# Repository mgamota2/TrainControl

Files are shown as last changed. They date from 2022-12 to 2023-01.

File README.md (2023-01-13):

# TrainControl

## Hardware

Wall Adapter - 18V DC Output
https://www.digikey.com/en/products/detail/triad-magnetics/WSU180-1000/3094965

Power Plug
https://www.digikey.com/en/products/detail/w%C3%BCrth-elektronik/694106301002/5047522

L293D H-Bridge
https://www.digikey.com/en/products/detail/stmicroelectronics/L293D/634700

18V-5V Converter
https://www.digikey.com/en/products/detail/mornsun-america-llc/URB4805S-3WR3/16348323

Raspberry Pi Pico W
https://www.digikey.com/en/products/detail/raspberry-pi/SC0918/16608263

MOSFETs(NMOS)
https://www.mouser.com/ProductDetail/Panjit/PJA3404_R1_00001?qs=sPbYRqrBIVkiUO9ZInE3tw%3D%3D

Cap(100uF)
https://www.digikey.com/en/products/detail/panasonic-electronic-components/ECA-1HM101B/268482

Cap(0.1uF)
https://www.mouser.com/ProductDetail/KEMET/C1210C104K1RAC?qs=0OaNwhvMTe1%2FSOzgnjC6ew%3D%3D

Cap(1 uF)
https://www.mouser.com/ProductDetail/Samsung-Electro-Mechanics/CL32B105KBHNNNE?qs=349EhDEZ59rXY4nCVEMdbA%3D%3D

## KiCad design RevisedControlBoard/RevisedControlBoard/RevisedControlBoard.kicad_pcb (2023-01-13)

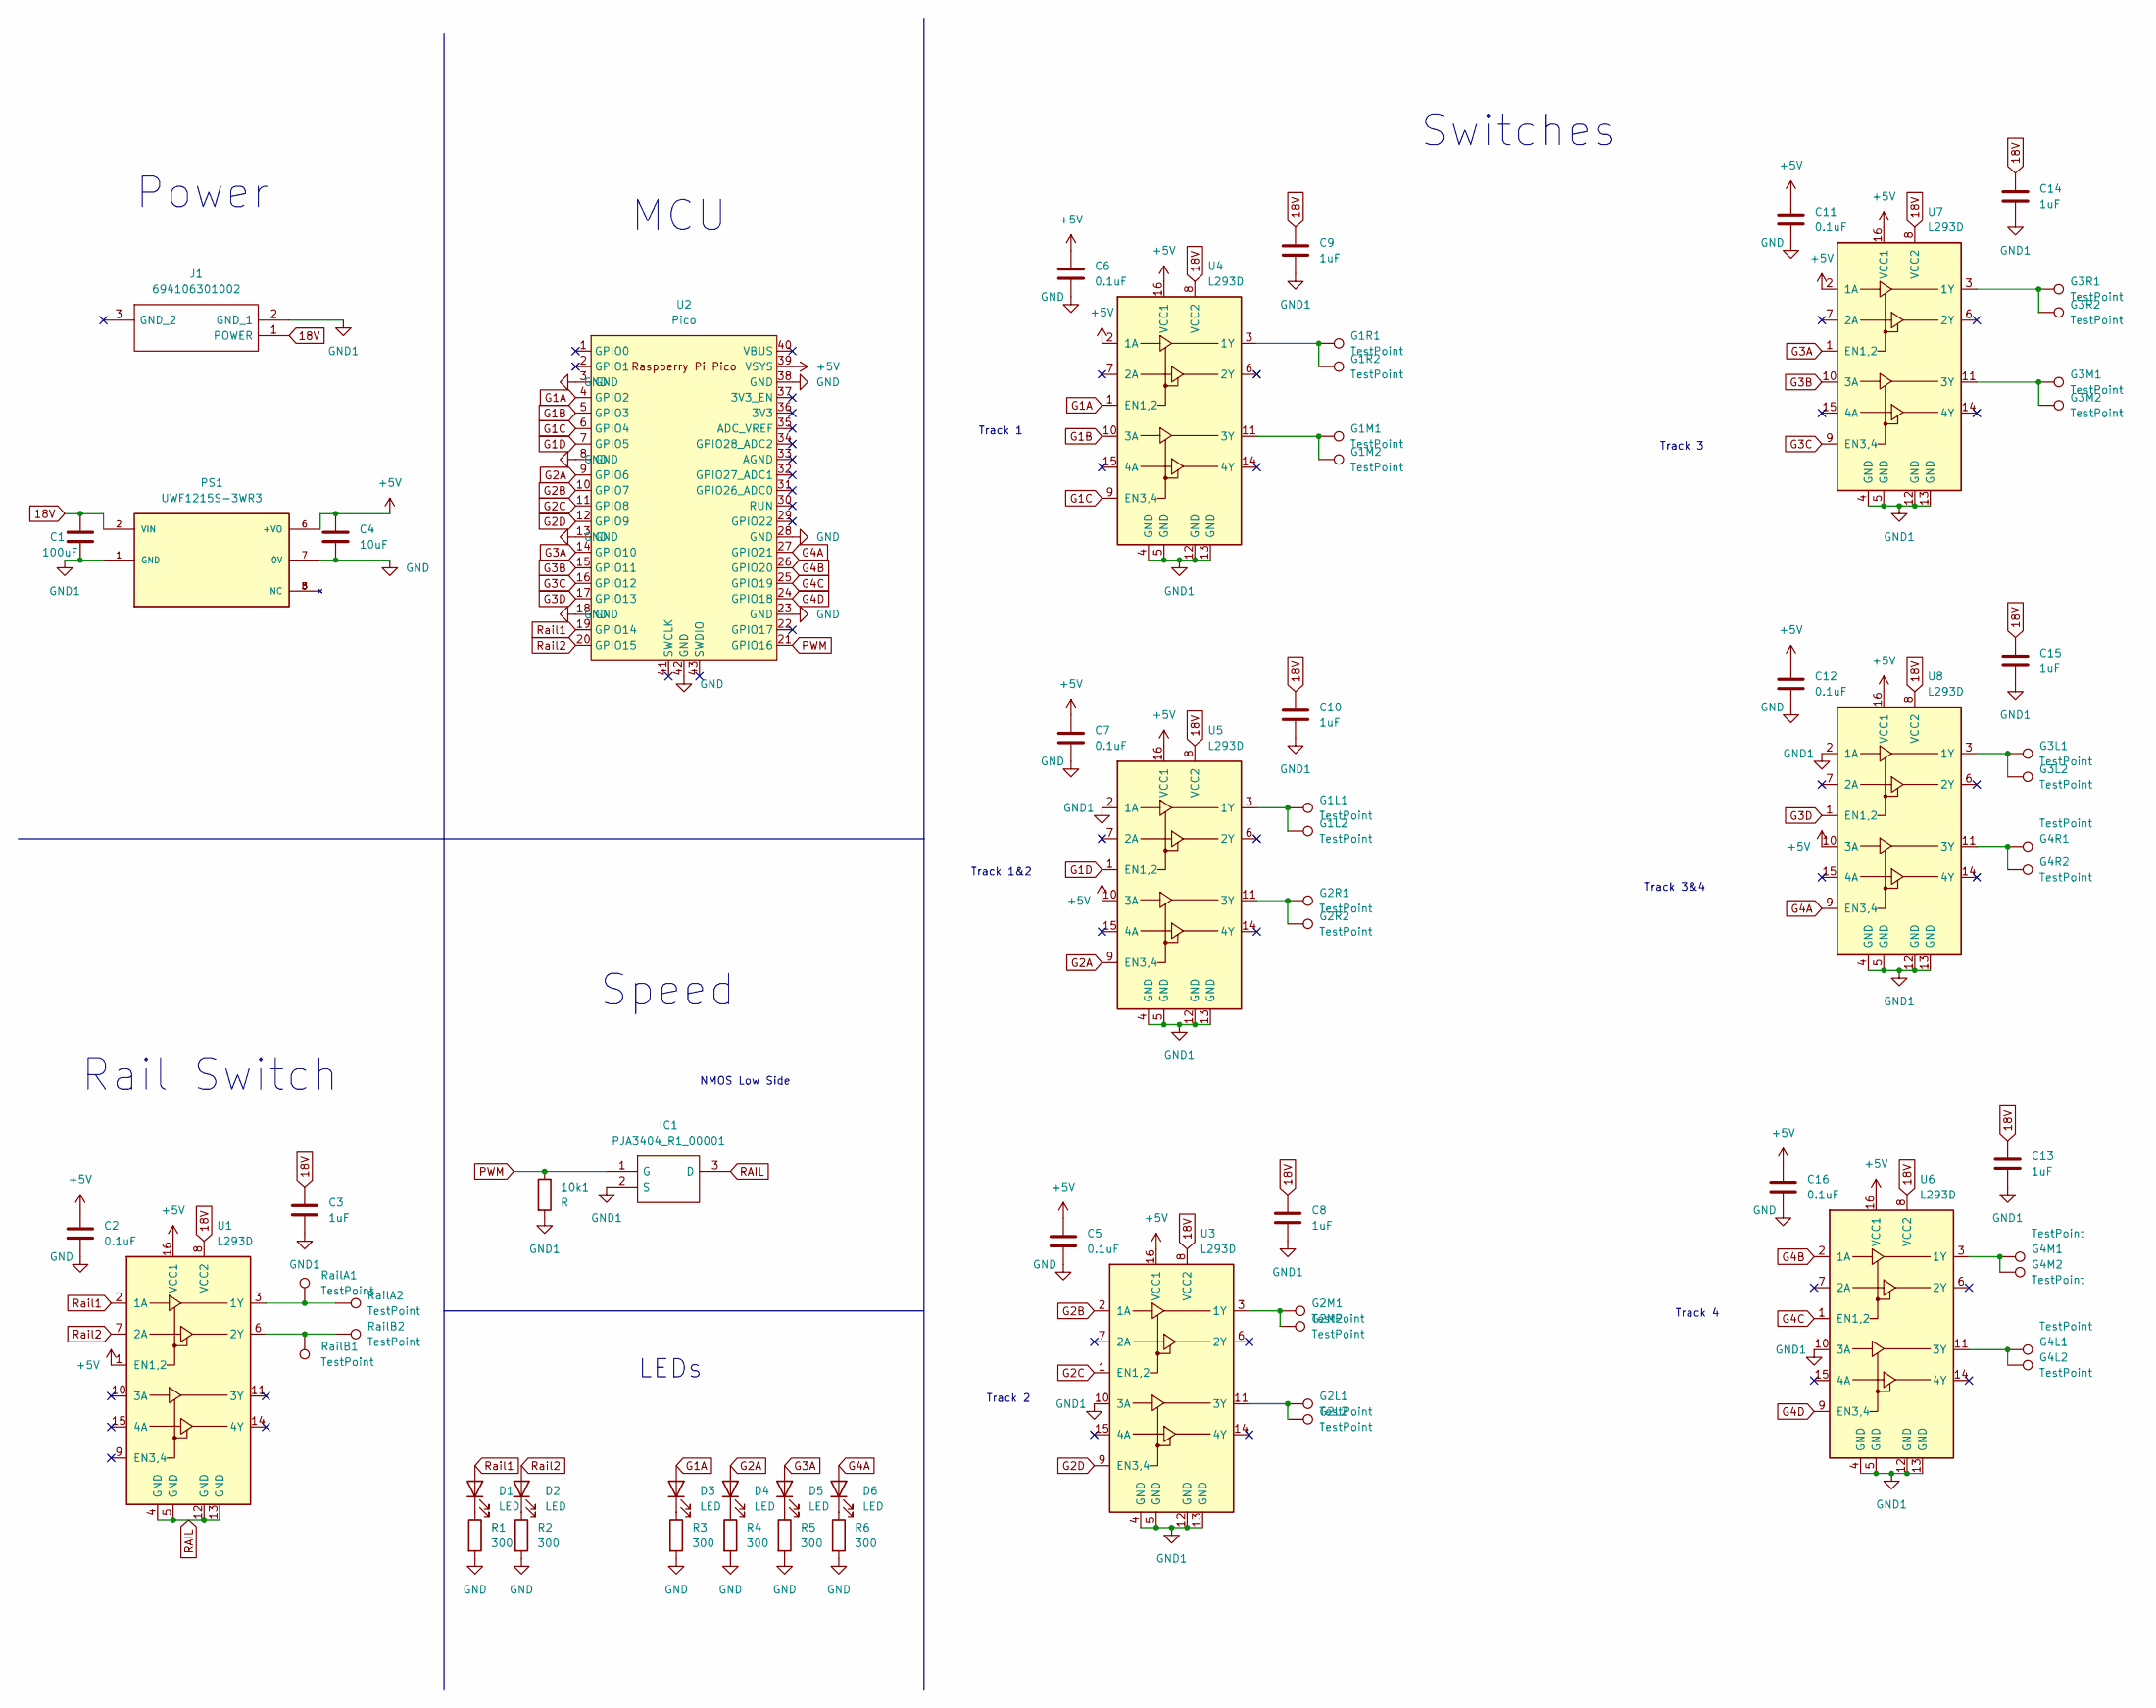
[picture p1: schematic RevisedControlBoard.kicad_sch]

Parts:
10k1: R; R_Axial_DIN0204_L3.6mm_D1.6mm_P7.62mm_Horizontal
C1: 100uF; CP_Radial_D10.0mm_P7.50mm
C2, C5, C6, C7, C11, C12, C16: 0.1uF; C_1210_3225Metric
C3, C8, C9, C10, C13, C14, C15: 1uF; C_1210_3225Metric
C4: 10uF; CP_Radial_D10.0mm_P7.50mm
D1, D2, D3, D4, D5, D6: LED; LED_D3.0mm
G1L1, G1L2, G1M1, G1M2, G1R1, G1R2, G2L1, G2L2, G2M1, G2M2, G2R1, G2R2, G3L1, G3L2, G3M1, G3M2, G3R1, G3R2, G4L1, G4L2, G4M1, G4M2, G4R1, G4R2: TestPoint; TestPoint_Pad_2.5x2.5mm
IC1: PJA3404_R1_00001; SOT95P240X110-3N; Mouser Part Number 241-PJA3404_R1_00001
J1: 694106301002; 694106301002_1; Mouser Part Number 710-694106301002
PS1: UWF1215S-3WR3; CONV_UWF1215S-3WR3; PARTREV 2020.08.11-A/1
R1, R2, R3, R4, R5, R6: 300; R_Axial_DIN0204_L3.6mm_D1.6mm_P7.62mm_Horizontal
RailA1, RailA2: TestPoint; TestPoint_Pad_2.5x2.5mm
RailB1, RailB2: TestPoint; TestPoint_Pad_2.5x2.5mm
U1, U3, U4, U5, U6, U7, U8: L293D; DIP-16_W7.62mm
U2: Pico; RPi_Pico_SMD_TH

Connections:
18V: C1.1, C3.1, C8.1, C9.1, C10.1, C13.1, C14.1, C15.1, J1.1 (POWER), PS1.2 (VIN), U1.8 (VCC2), U3.8 (VCC2), U4.8 (VCC2), U5.8 (VCC2), U6.8 (VCC2), U7.8 (VCC2), U8.8 (VCC2)
+5V: C2.1, C4.1, C5.1, C6.1, C7.1, C11.1, C12.1, C16.1, PS1.6 (+VO), U1.1 (EN1,2), U1.16 (VCC1), U2.39 (VSYS), U3.16 (VCC1), U4.2 (1A), U4.16 (VCC1), U5.10 (3A), U5.16 (VCC1), U6.16 (VCC1), U7.2 (1A), U7.16 (VCC1), U8.10 (3A), U8.16 (VCC1)
G1A: D3.2 (A), U2.4 (GPIO2), U4.1 (EN1,2)
G1B: U2.5 (GPIO3), U4.10 (3A)
G1C: U2.6 (GPIO4), U4.9 (EN3,4)
G1D: U2.7 (GPIO5), U5.1 (EN1,2)
G2A: D4.2 (A), U2.9 (GPIO6), U5.9 (EN3,4)
G2B: U2.10 (GPIO7), U3.2 (1A)
G2C: U2.11 (GPIO8), U3.1 (EN1,2)
G2D: U2.12 (GPIO9), U3.9 (EN3,4)
G3A: D5.2 (A), U2.14 (GPIO10), U7.1 (EN1,2)
G3B: U2.15 (GPIO11), U7.10 (3A)
G3C: U2.16 (GPIO12), U7.9 (EN3,4)
G3D: U2.17 (GPIO13), U8.1 (EN1,2)
G4A: D6.2 (A), U2.27 (GPIO21), U8.9 (EN3,4)
G4B: U2.26 (GPIO20), U6.2 (1A)
G4C: U2.25 (GPIO19), U6.1 (EN1,2)
G4D: U2.24 (GPIO18), U6.9 (EN3,4)
GND: C2.2, C4.2, C5.2, C6.2, C7.2, C11.2, C12.2, C16.2, PS1.7 (0V), R1.2, R2.2, R3.2, R4.2, R5.2, R6.2, U2.3 (GND), U2.8 (GND), U2.13 (GND), U2.18 (GND), U2.23 (GND), U2.28 (GND), U2.38 (GND), U2.42 (GND)
GND1: 10k1.2, C1.2, C3.2, C8.2, C9.2, C10.2, C13.2, C14.2, C15.2, IC1.2 (S), J1.2 (GND_1), PS1.1 (GND), U3.4 (GND), U3.5 (GND), U3.10 (3A), U3.12 (GND), U3.13 (GND), U4.4 (GND), U4.5 (GND), U4.12 (GND), U4.13 (GND), U5.2 (1A), U5.4 (GND), U5.5 (GND), U5.12 (GND), U5.13 (GND), U6.4 (GND), U6.5 (GND), U6.10 (3A), U6.12 (GND), U6.13 (GND), U7.4 (GND), U7.5 (GND), U7.12 (GND), U7.13 (GND), U8.2 (1A), U8.4 (GND), U8.5 (GND), U8.12 (GND), U8.13 (GND)
unnamed: D1.1 (K), R1.1
unnamed: D2.1 (K), R2.1
unnamed: D3.1 (K), R3.1
unnamed: D4.1 (K), R4.1
unnamed: D5.1 (K), R5.1
unnamed: D6.1 (K), R6.1
unnamed: G1L1.1, G1L2.1, U5.3 (1Y)
unnamed: G1M1.1, G1M2.1, U4.11 (3Y)
unnamed: G1R1.1, G1R2.1, U4.3 (1Y)
unnamed: G2L1.1, G2L2.1, U3.11 (3Y)
unnamed: G2M1.1, G2M2.1, U3.3 (1Y)
unnamed: G2R1.1, G2R2.1, U5.11 (3Y)
unnamed: G3L1.1, G3L2.1, U8.3 (1Y)
unnamed: G3M1.1, G3M2.1, U7.11 (3Y)
unnamed: G3R1.1, G3R2.1, U7.3 (1Y)
unnamed: G4L1.1, G4L2.1, U6.11 (3Y)
unnamed: G4M1.1, G4M2.1, U6.3 (1Y)
unnamed: G4R1.1, G4R2.1, U8.11 (3Y)
unnamed: RailA1.1, RailA2.1, U1.3 (1Y)
unnamed: RailB1.1, RailB2.1, U1.6 (2Y)
PWM: 10k1.1, IC1.1 (G), U2.21 (GPIO16)
RAIL: IC1.3 (D), U1.4 (GND), U1.5 (GND), U1.12 (GND), U1.13 (GND)
Rail1: D1.2 (A), U1.2 (1A), U2.19 (GPIO14)
Rail2: D2.2 (A), U1.7 (2A), U2.20 (GPIO15)

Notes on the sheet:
MCU
Power
LEDs
Track 1&2
Track 3&4
Track 3
Track 2
Switches
Track 4
Track 1
NMOS Low Side
Speed
Rail Switch

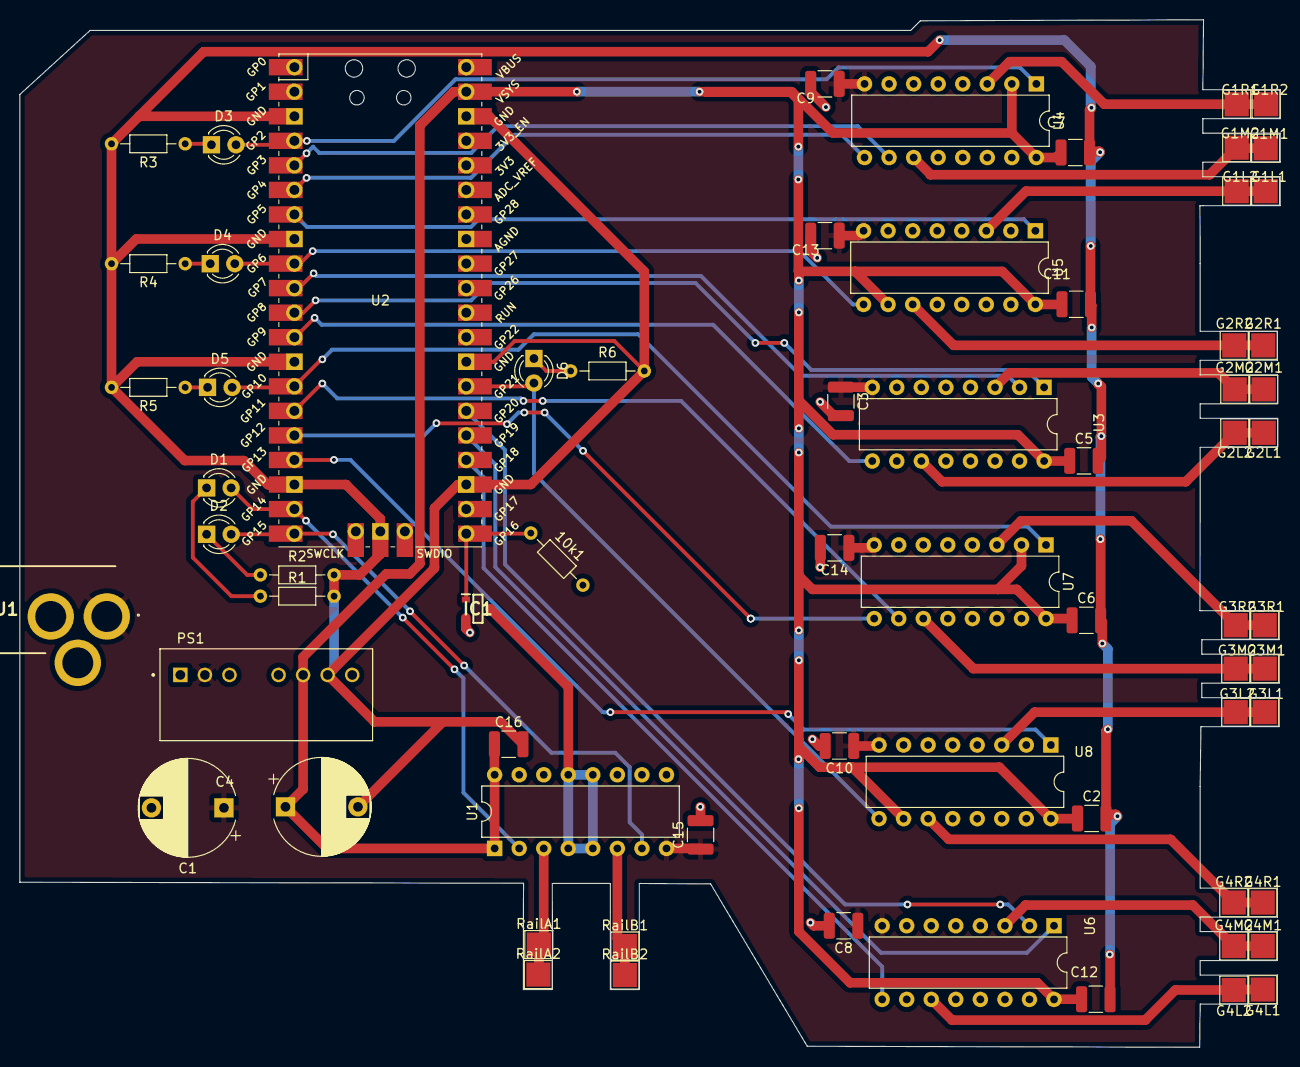
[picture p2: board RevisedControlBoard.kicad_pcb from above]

Board: 2 copper layers, 130.4 x 106.3 mm, 68 parts (0 on the bottom side), 44 nets.

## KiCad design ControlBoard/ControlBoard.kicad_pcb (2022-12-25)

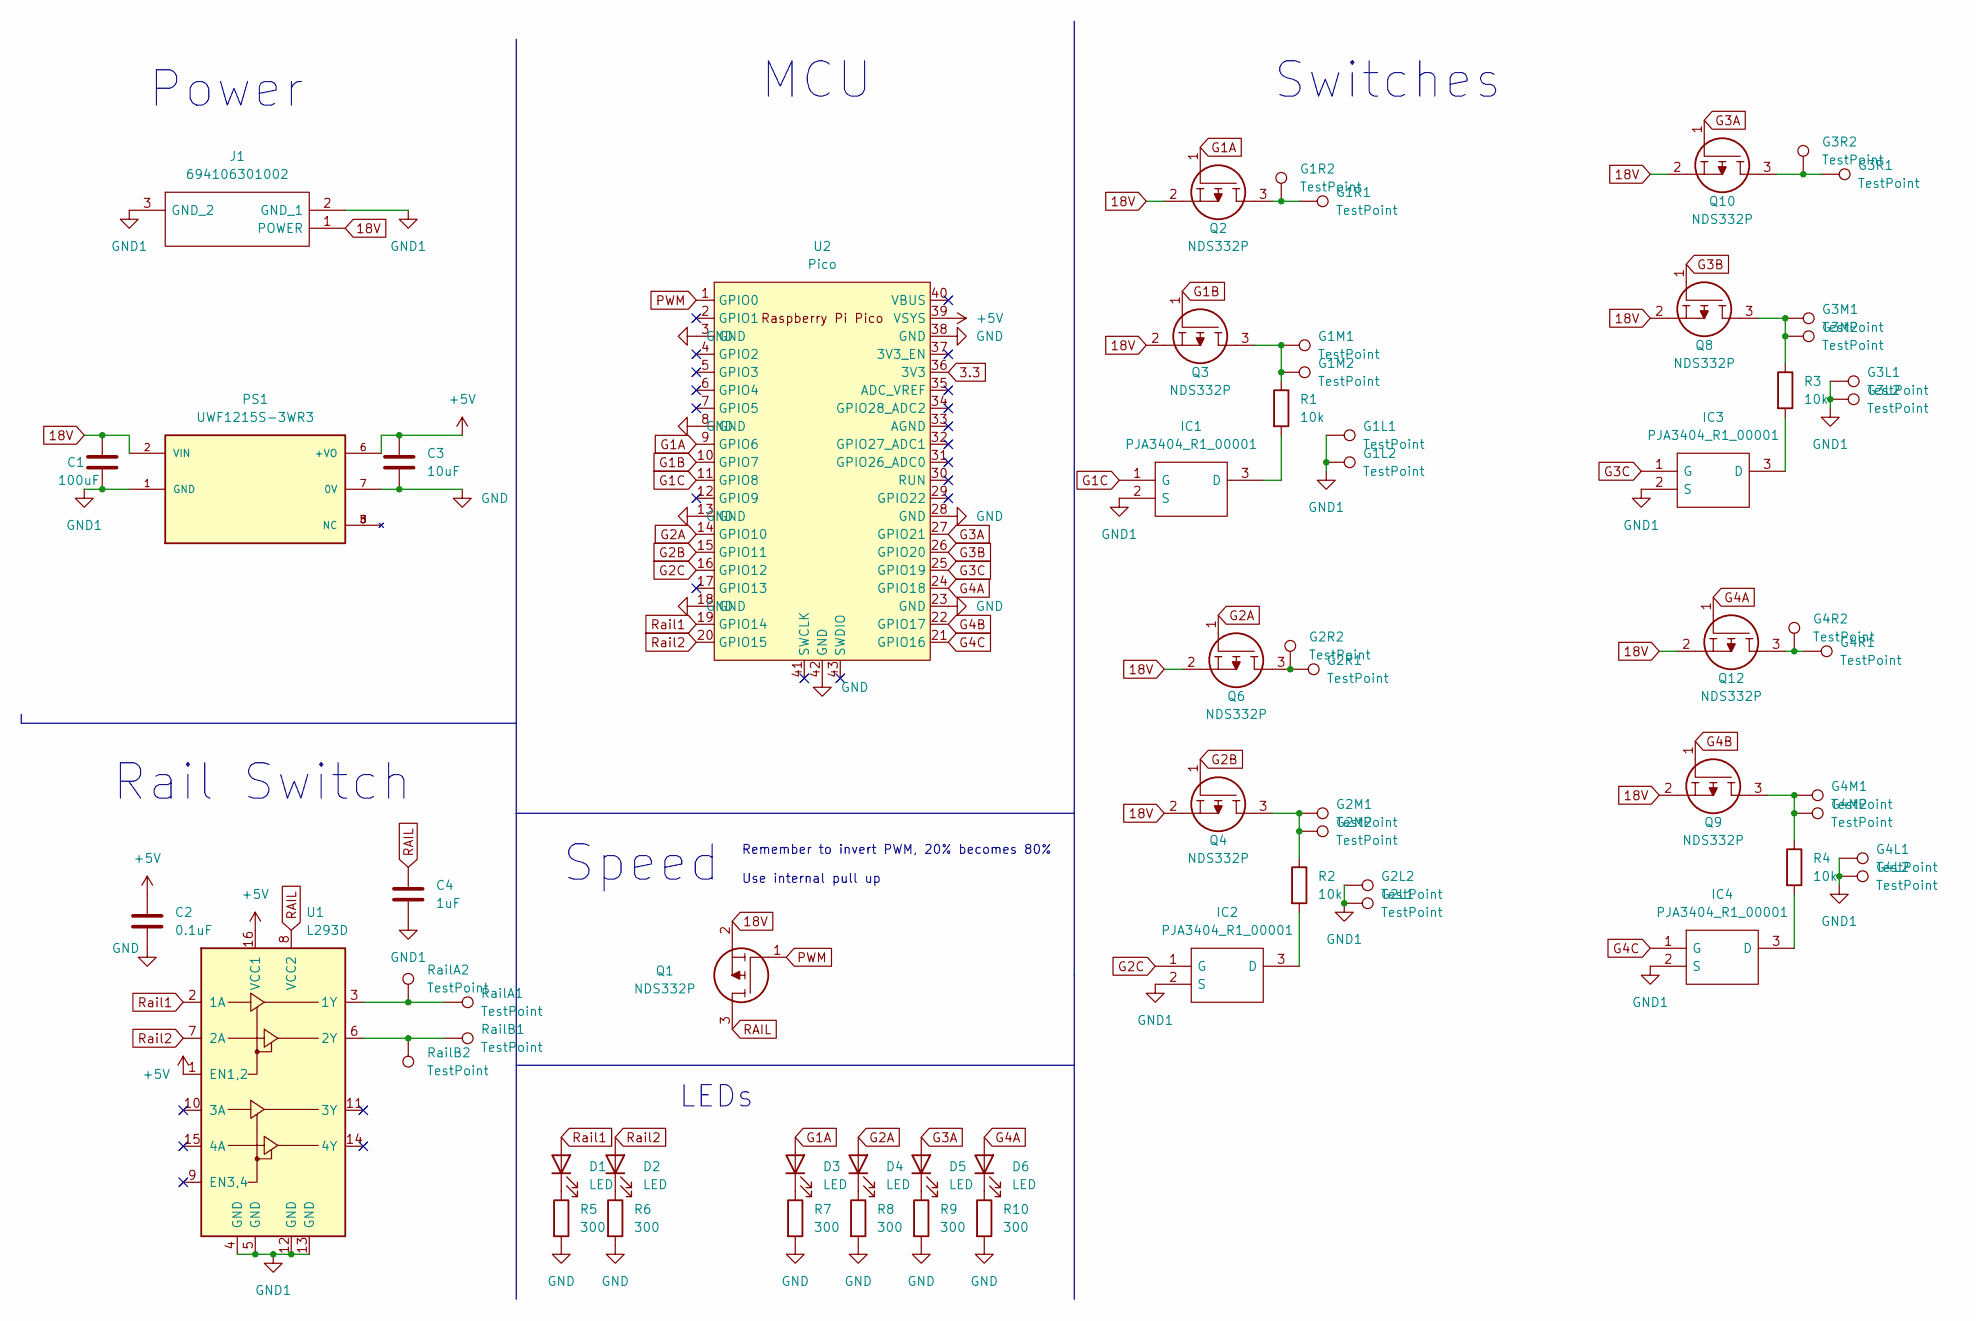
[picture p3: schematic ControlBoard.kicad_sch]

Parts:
C1: 100uF; CP_Radial_D10.0mm_P7.50mm
C2: 0.1uF; CP_Radial_D10.0mm_P7.50mm
C3: 10uF; CP_Radial_D10.0mm_P7.50mm
C4: 1uF; CP_Radial_D10.0mm_P7.50mm
D1, D2, D3, D4, D5, D6: LED; LED_D3.0mm
G1L1, G1L2, G1M1, G1M2, G1R1, G1R2, G2L1, G2L2, G2M1, G2M2, G2R1, G2R2, G3L1, G3L2, G3M1, G3M2, G3R1, G3R2, G4L1, G4L2, G4M1, G4M2, G4R1, G4R2: TestPoint; TestPoint_Pad_2.5x2.5mm
IC1, IC2, IC3, IC4: PJA3404_R1_00001; SOT95P240X110-3N; Mouser Part Number 241-PJA3404_R1_00001
J1: 694106301002; 694106301002_1; Mouser Part Number 710-694106301002
PS1: UWF1215S-3WR3; CONV_UWF1215S-3WR3; PARTREV 2020.08.11-A/1
Q1, Q2, Q3, Q4, Q6, Q8, Q9, Q10, Q12: NDS332P; SOT95P237X112-3N; Mouser Part Number 512-NDS332P
R1, R2, R3, R4: 10k; R_Axial_DIN0204_L3.6mm_D1.6mm_P7.62mm_Horizontal
R5, R6, R7, R8, R9, R10: 300; R_Axial_DIN0204_L3.6mm_D1.6mm_P7.62mm_Horizontal
RailA1, RailA2: TestPoint; TestPoint_Pad_2.5x2.5mm
RailB1, RailB2: TestPoint; TestPoint_Pad_2.5x2.5mm
U1: L293D; DIP-16_W7.62mm
U2: Pico; RPi_Pico_SMD_TH

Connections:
3.3: U2.36 (3V3)
18V: C1.1, J1.1 (POWER), PS1.2 (VIN), Q1.2, Q2.2, Q3.2, Q4.2, Q6.2, Q8.2, Q9.2, Q10.2, Q12.2
+5V: C2.1, C3.1, PS1.6 (+VO), U1.1 (EN1,2), U1.16 (VCC1), U2.39 (VSYS)
G1A: D3.2 (A), Q2.1, U2.9 (GPIO6)
G1B: Q3.1, U2.10 (GPIO7)
G1C: IC1.1 (G), U2.11 (GPIO8)
G2A: D4.2 (A), Q6.1, U2.14 (GPIO10)
G2B: Q4.1, U2.15 (GPIO11)
G2C: IC2.1 (G), U2.16 (GPIO12)
G3A: D5.2 (A), Q10.1, U2.27 (GPIO21)
G3B: Q8.1, U2.26 (GPIO20)
G3C: IC3.1 (G), U2.25 (GPIO19)
G4A: D6.2 (A), Q12.1, U2.24 (GPIO18)
G4B: Q9.1, U2.22 (GPIO17)
G4C: IC4.1 (G), U2.21 (GPIO16)
GND: C2.2, C3.2, PS1.7 (0V), R5.2, R6.2, R7.2, R8.2, R9.2, R10.2, U2.3 (GND), U2.8 (GND), U2.13 (GND), U2.18 (GND), U2.23 (GND), U2.28 (GND), U2.38 (GND), U2.42 (GND)
GND1: C1.2, C4.2, G1L1.1, G1L2.1, G2L1.1, G2L2.1, G3L1.1, G3L2.1, G4L1.1, G4L2.1, IC1.2 (S), IC2.2 (S), IC3.2 (S), IC4.2 (S), J1.2 (GND_1), J1.3 (GND_2), PS1.1 (GND), U1.4 (GND), U1.5 (GND), U1.12 (GND), U1.13 (GND)
unnamed: D1.1 (K), R5.1
unnamed: D2.1 (K), R6.1
unnamed: D3.1 (K), R7.1
unnamed: D4.1 (K), R8.1
unnamed: D5.1 (K), R9.1
unnamed: D6.1 (K), R10.1
unnamed: G1M1.1, G1M2.1, Q3.3, R1.1
unnamed: G1R1.1, G1R2.1, Q2.3
unnamed: G2M1.1, G2M2.1, Q4.3, R2.1
unnamed: G2R1.1, G2R2.1, Q6.3
unnamed: G3M1.1, G3M2.1, Q8.3, R3.1
unnamed: G3R1.1, G3R2.1, Q10.3
unnamed: G4M1.1, G4M2.1, Q9.3, R4.1
unnamed: G4R1.1, G4R2.1, Q12.3
unnamed: IC1.3 (D), R1.2
unnamed: IC2.3 (D), R2.2
unnamed: IC3.3 (D), R3.2
unnamed: IC4.3 (D), R4.2
unnamed: RailA1.1, RailA2.1, U1.3 (1Y)
unnamed: RailB1.1, RailB2.1, U1.6 (2Y)
PWM: Q1.1, U2.1 (GPIO0)
RAIL: C4.1, Q1.3, U1.8 (VCC2)
Rail1: D1.2 (A), U1.2 (1A), U2.19 (GPIO14)
Rail2: D2.2 (A), U1.7 (2A), U2.20 (GPIO15)

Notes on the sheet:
Remember to invert PWM, 20% becomes 80% Use internal pull up
MCU
Power
Speed
Switches
Rail Switch
LEDs

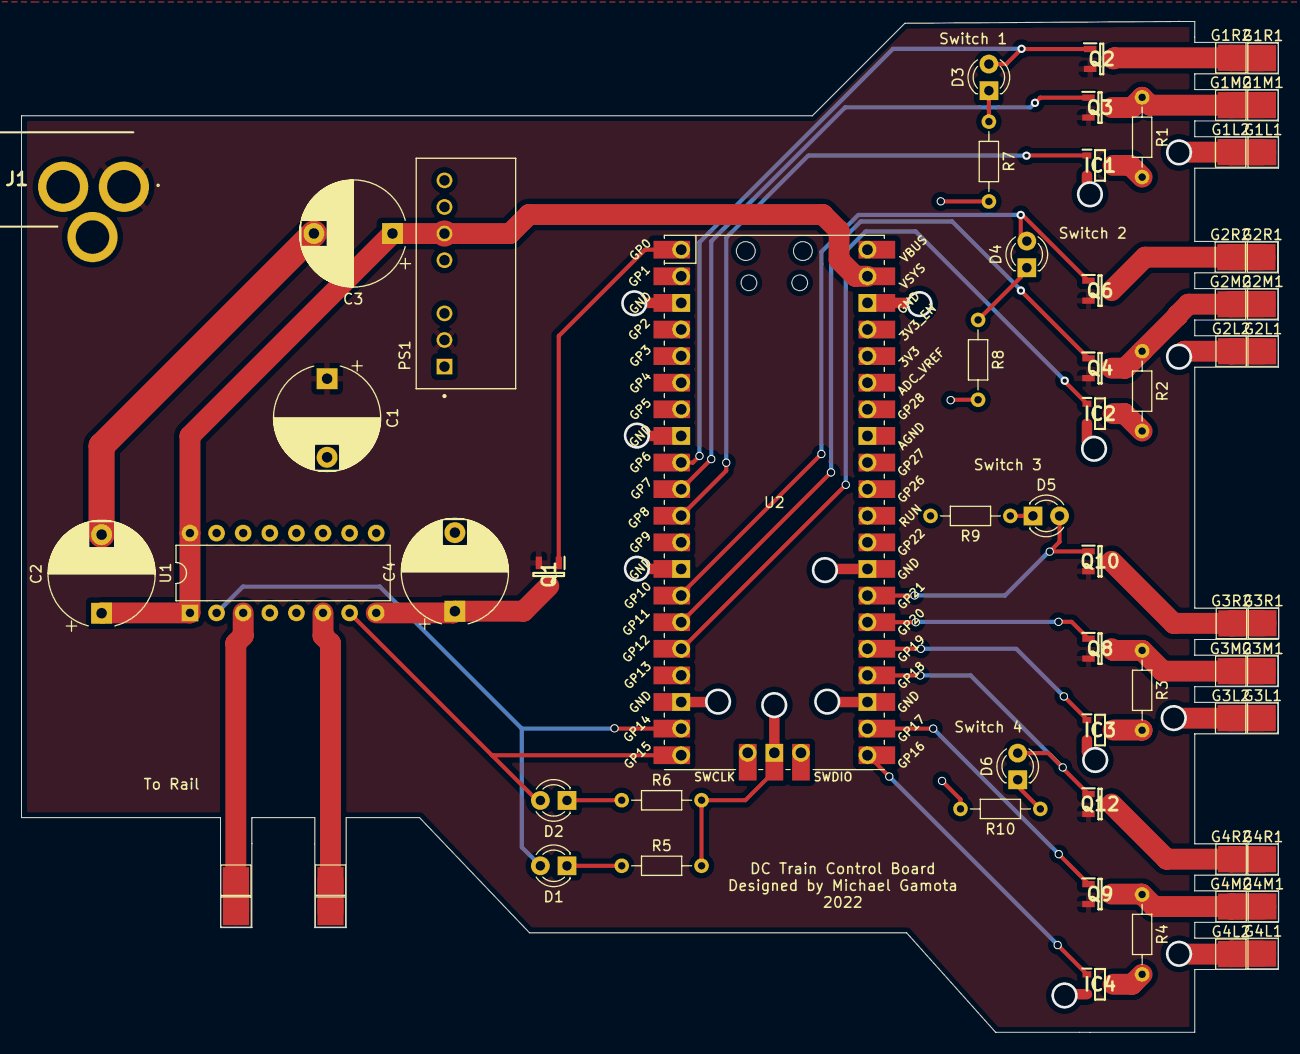
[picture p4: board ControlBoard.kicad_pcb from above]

Board: 2 copper layers, 120.0 x 96.5 mm, 65 parts (0 on the bottom side), 40 nets.

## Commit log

2022-12-24 Final parts list
    [ControlBoard.kicad_pcb, ControlBoard.kicad_sch]
2022-12-25 Finalized layout
    [ControlBoard-B_Cu.gbr, ControlBoard-B_Mask.gbr, ControlBoard-B_Paste.gbr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]
2023-01-13 Added revised
    [ControlBoard-B_Cu.gbr, ControlBoard-B_Mask.gbr, ControlBoard-B_Paste.gbr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]
2023-01-13 Updated BOM
